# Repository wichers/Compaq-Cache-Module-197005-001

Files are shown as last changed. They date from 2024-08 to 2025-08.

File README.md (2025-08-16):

# Compaq 197005-001 Cache Module reproduction
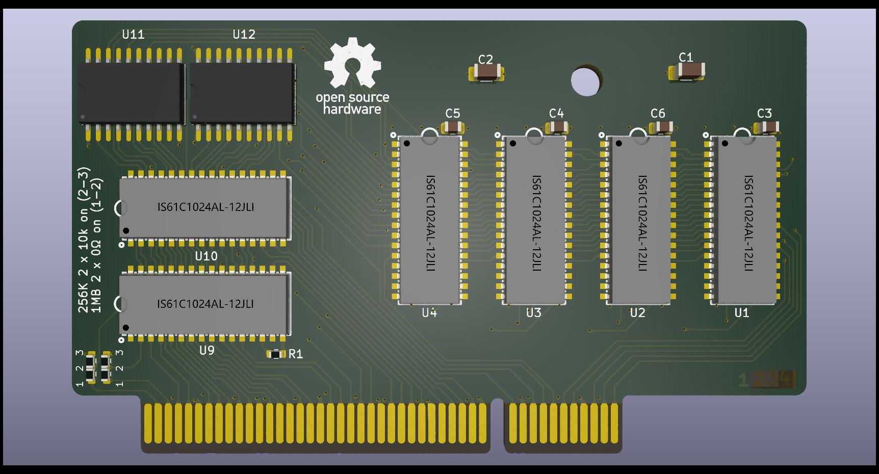
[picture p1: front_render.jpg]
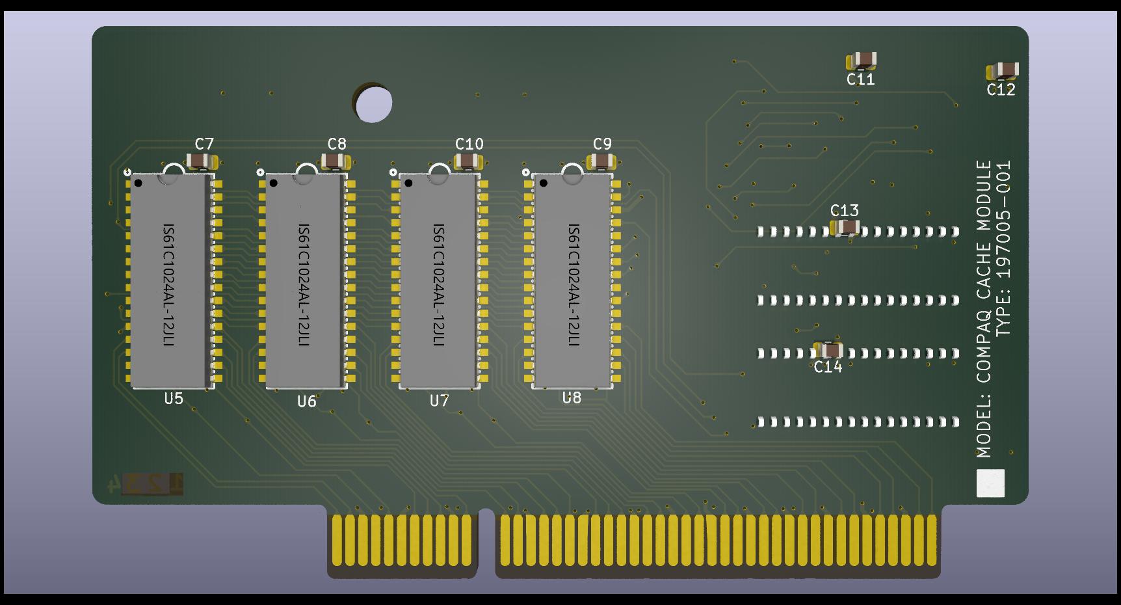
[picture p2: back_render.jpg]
[](/front_render.png?raw=true) [](/back_render.png?raw=true)

Reverse Engineered non standard 256KB/1MB L2 Cache Module for use in:

- [Compaq ProLinea 4/66 (164560-001)](https://theretroweb.com/motherboards/s/compaq-prolinea-4-66)
- [Compaq Presario 833CDS/850/850CDS/860CDS/866 (197023-001)](https://theretroweb.com/motherboards/s/compaq-presario-800)
- [Compaq Presario 700-900 series](https://theretroweb.com/motherboards/s/compaq-presario-700-900-series-486)

# Resources
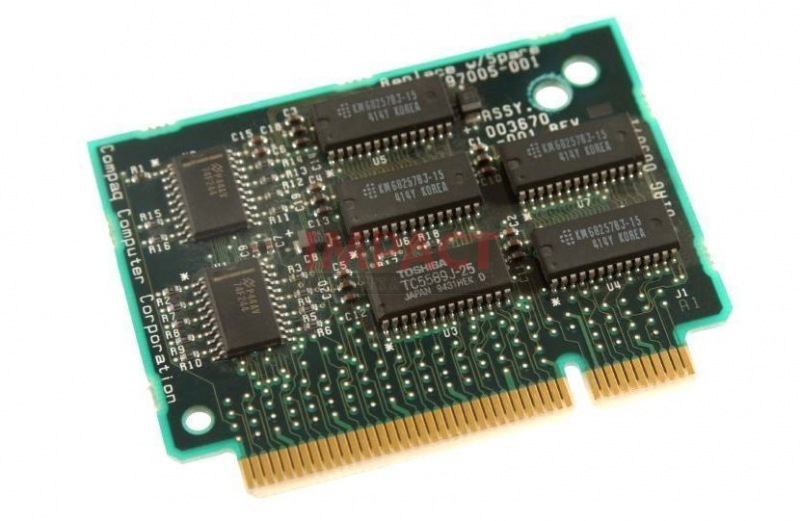
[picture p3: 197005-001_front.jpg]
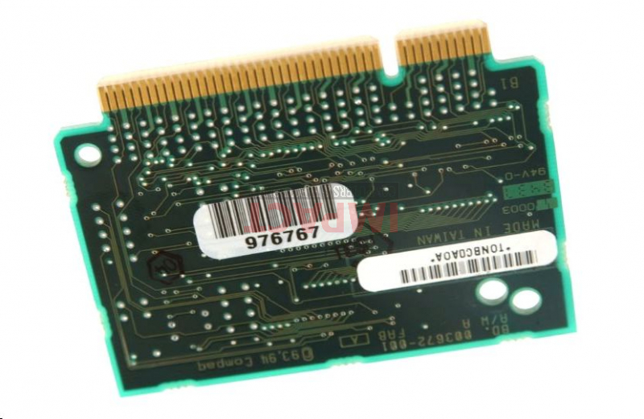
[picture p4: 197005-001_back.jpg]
Original 128KB module [front ](/197005-001_front.jpg?raw=true), [back ](/197005-001_back.jpg?raw=true)

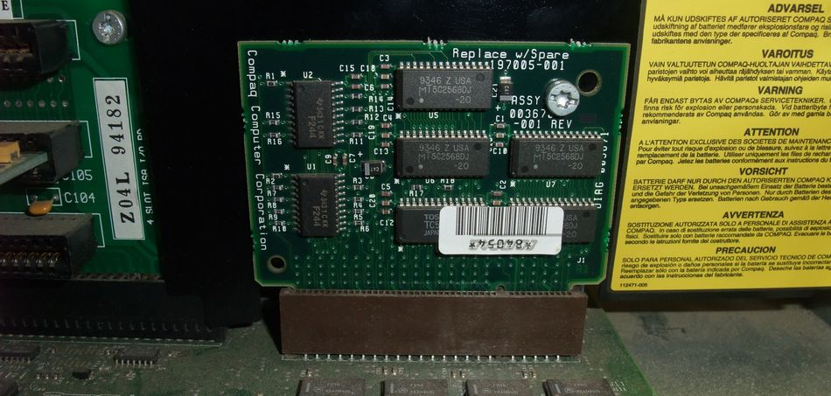
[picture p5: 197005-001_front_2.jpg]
[plugged into Prolinea 4/100](/197005-001_front_2.jpg?raw=true)

-----
This project was possible with help provided by rasz_pl - creator of the - [FIC-486-GAC-2 Cache Module reproduction](https://github.com/raszpl/FIC-486-GAC-2-Cache-Module). Huge thank you for inspiration and taking time to review.

[VL82C481 datasheet](/vl82c481-633364566fabe183309250.pdf)

[VESA VLB slot pinout](/VLB_pins.png) [VESA VLB slot dimensions](/vlb-edge-conn.png)

# Progress report

16/8/2025: Added switch to set memory size

31/8/2024: Added support for switchable 256KB/1MB

28/8/2024: First version up for testing.

23/8/2024: Project start. Figuring out the pinout and matching to datasheet.

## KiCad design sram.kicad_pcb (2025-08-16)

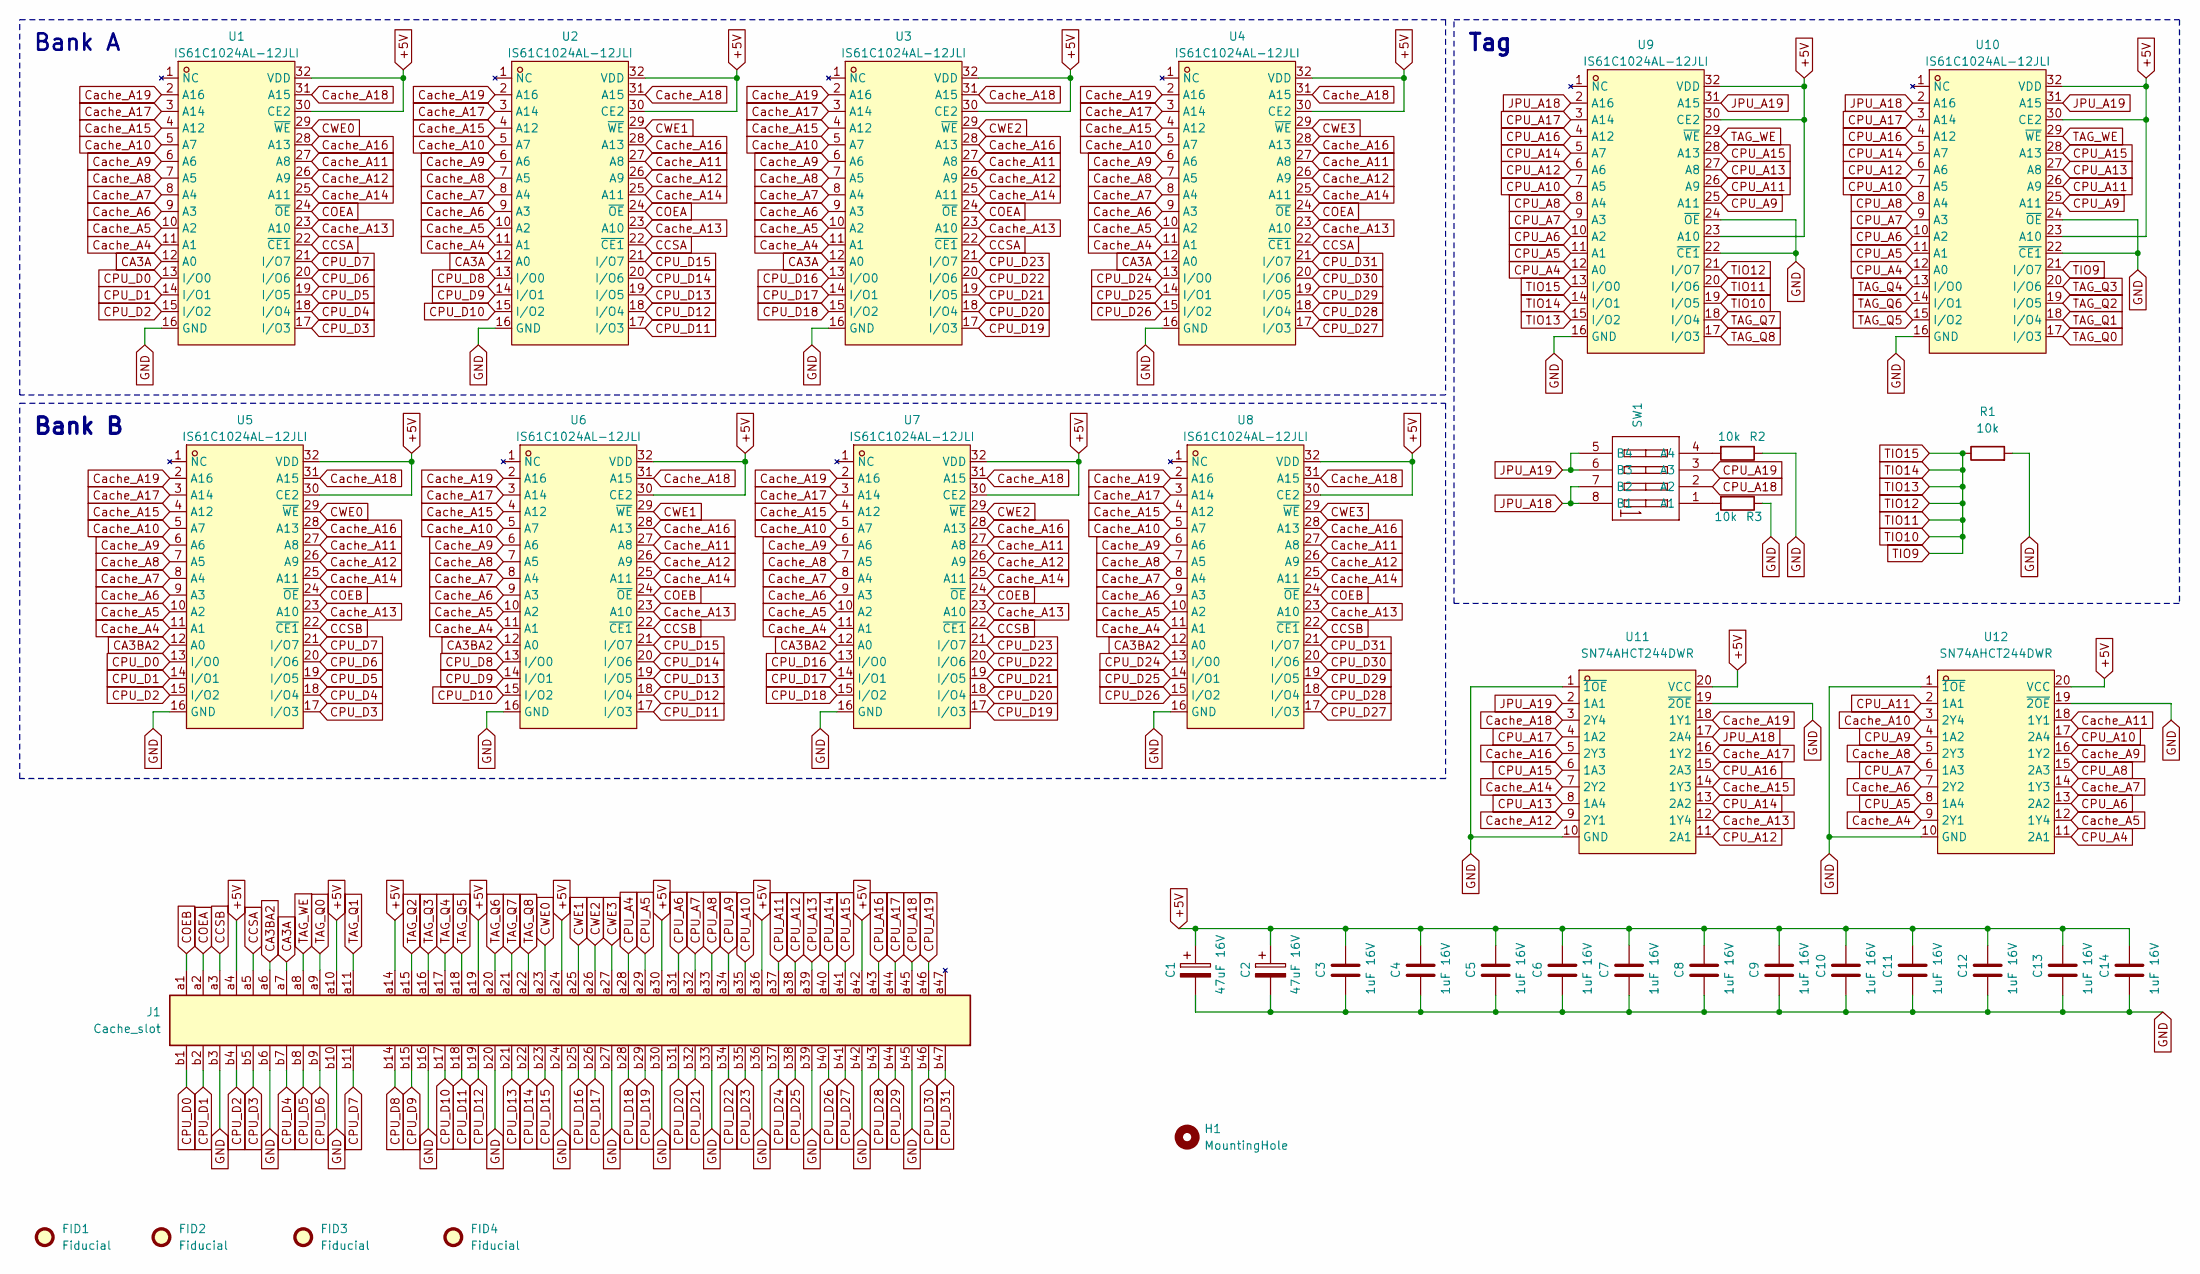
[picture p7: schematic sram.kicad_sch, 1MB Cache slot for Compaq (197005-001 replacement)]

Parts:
C1, C2: 47uF 16V; C_1206_3216Metric_Pad1.33x1.80mm_HandSolder
C3, C4, C5, C6, C7, C8, C9, C10, C11, C12, C13, C14: 1uF 16V; C_0805_2012Metric
FID1, FID2, FID3, FID4: Fiducial; Fiducial_0.5mm_Mask1mm
H1: MountingHole; MountingHole_4mm
J1: Cache_slot; Cache slot
R1, R2, R3: 10k; R_0603_1608Metric
SW1: DSIC04TSGET; SW-SMD_8P-L11.1-W6.2-P2.54-LS9.8; LCSC Part C126850
U1, U2, U3, U4, U5, U6, U7, U8, U9, U10: IS61C1024AL-12JLI; SOJ-32_L21.0-W7.6-P1.27-LS8.5-BL; LCSC Part C412832
U11, U12: SN74AHCT244DWR; SOIC-20_L12.8-W7.5-P1.27-LS10.3-BL; LCSC Part C2675568

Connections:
+5V: C1.1, C2.1, C3.1, C4.1, C5.1, C6.1, C7.1, C8.1, C9.1, C10.1, C11.1, C12.1, C13.1, C14.1, J1.a4, J1.a10, J1.a14, J1.a19, J1.a24, J1.a30, J1.a36, J1.a42, U1.30 (CE2), U1.32 (VDD), U2.30 (CE2), U2.32 (VDD), U3.30 (CE2), U3.32 (VDD), U4.30 (CE2), U4.32 (VDD), U5.30 (CE2), U5.32 (VDD), U6.30 (CE2), U6.32 (VDD), U7.30 (CE2), U7.32 (VDD), U8.30 (CE2), U8.32 (VDD), U9.23 (A10), U9.30 (CE2), U9.32 (VDD), U10.23 (A10), U10.30 (CE2), U10.32 (VDD), U11.20 (VCC), U12.20 (VCC)
CA3A: J1.a7, U1.12 (A0), U2.12 (A0), U3.12 (A0), U4.12 (A0)
CA3BA2: J1.a6, U5.12 (A0), U6.12 (A0), U7.12 (A0), U8.12 (A0)
CCSA: J1.a5, U1.22 (~CE1), U2.22 (~CE1), U3.22 (~CE1), U4.22 (~CE1)
CCSB: J1.a3, U5.22 (~CE1), U6.22 (~CE1), U7.22 (~CE1), U8.22 (~CE1)
COEA: J1.a2, U1.24 (~OE), U2.24 (~OE), U3.24 (~OE), U4.24 (~OE)
COEB: J1.a1, U5.24 (~OE), U6.24 (~OE), U7.24 (~OE), U8.24 (~OE)
CPU_A4: J1.a28, U9.12 (A0), U10.12 (A0), U12.11 (2A1)
CPU_A5: J1.a29, U9.11 (A1), U10.11 (A1), U12.8 (1A4)
CPU_A6: J1.a31, U9.10 (A2), U10.10 (A2), U12.13 (2A2)
CPU_A7: J1.a32, U9.9 (A3), U10.9 (A3), U12.6 (1A3)
CPU_A8: J1.a33, U9.8 (A4), U10.8 (A4), U12.15 (2A3)
CPU_A9: J1.a34, U9.25 (A11), U10.25 (A11), U12.4 (1A2)
CPU_A10: J1.a35, U9.7 (A5), U10.7 (A5), U12.17 (2A4)
CPU_A11: J1.a37, U9.26 (A9), U10.26 (A9), U12.2 (1A1)
CPU_A12: J1.a38, U9.6 (A6), U10.6 (A6), U11.11 (2A1)
CPU_A13: J1.a39, U9.27 (A8), U10.27 (A8), U11.8 (1A4)
CPU_A14: J1.a40, U9.5 (A7), U10.5 (A7), U11.13 (2A2)
CPU_A15: J1.a41, U9.28 (A13), U10.28 (A13), U11.6 (1A3)
CPU_A16: J1.a43, U9.4 (A12), U10.4 (A12), U11.15 (2A3)
CPU_A17: J1.a44, U9.3 (A14), U10.3 (A14), U11.4 (1A2)
CPU_A18: J1.a45, SW1.2 (A2)
CPU_A19: J1.a46, SW1.3 (A3)
CPU_D0: J1.b1, U1.13 (I/O0), U5.13 (I/O0)
CPU_D1: J1.b2, U1.14 (I/O1), U5.14 (I/O1)
CPU_D2: J1.b4, U1.15 (I/O2), U5.15 (I/O2)
CPU_D3: J1.b5, U1.17 (I/O3), U5.17 (I/O3)
CPU_D4: J1.b7, U1.18 (I/O4), U5.18 (I/O4)
CPU_D5: J1.b8, U1.19 (I/O5), U5.19 (I/O5)
CPU_D6: J1.b9, U1.20 (I/O6), U5.20 (I/O6)
CPU_D7: J1.b11, U1.21 (I/O7), U5.21 (I/O7)
CPU_D8: J1.b14, U2.13 (I/O0), U6.13 (I/O0)
CPU_D9: J1.b15, U2.14 (I/O1), U6.14 (I/O1)
CPU_D10: J1.b17, U2.15 (I/O2), U6.15 (I/O2)
CPU_D11: J1.b18, U2.17 (I/O3), U6.17 (I/O3)
CPU_D12: J1.b19, U2.18 (I/O4), U6.18 (I/O4)
CPU_D13: J1.b21, U2.19 (I/O5), U6.19 (I/O5)
CPU_D14: J1.b22, U2.20 (I/O6), U6.20 (I/O6)
CPU_D15: J1.b23, U2.21 (I/O7), U6.21 (I/O7)
CPU_D16: J1.b25, U3.13 (I/O0), U7.13 (I/O0)
CPU_D17: J1.b26, U3.14 (I/O1), U7.14 (I/O1)
CPU_D18: J1.b28, U3.15 (I/O2), U7.15 (I/O2)
CPU_D19: J1.b29, U3.17 (I/O3), U7.17 (I/O3)
CPU_D20: J1.b31, U3.18 (I/O4), U7.18 (I/O4)
CPU_D21: J1.b32, U3.19 (I/O5), U7.19 (I/O5)
CPU_D22: J1.b34, U3.20 (I/O6), U7.20 (I/O6)
CPU_D23: J1.b35, U3.21 (I/O7), U7.21 (I/O7)
CPU_D24: J1.b37, U4.13 (I/O0), U8.13 (I/O0)
CPU_D25: J1.b38, U4.14 (I/O1), U8.14 (I/O1)
CPU_D26: J1.b40, U4.15 (I/O2), U8.15 (I/O2)
CPU_D27: J1.b41, U4.17 (I/O3), U8.17 (I/O3)
CPU_D28: J1.b43, U4.18 (I/O4), U8.18 (I/O4)
CPU_D29: J1.b44, U4.19 (I/O5), U8.19 (I/O5)
CPU_D30: J1.b46, U4.20 (I/O6), U8.20 (I/O6)
CPU_D31: J1.b47, U4.21 (I/O7), U8.21 (I/O7)
CWE0: J1.a23, U1.29 (~WE), U5.29 (~WE)
CWE1: J1.a25, U2.29 (~WE), U6.29 (~WE)
CWE2: J1.a26, U3.29 (~WE), U7.29 (~WE)
CWE3: J1.a27, U4.29 (~WE), U8.29 (~WE)
Cache_A4: U1.11 (A1), U2.11 (A1), U3.11 (A1), U4.11 (A1), U5.11 (A1), U6.11 (A1), U7.11 (A1), U8.11 (A1), U12.9 (2Y1)
Cache_A5: U1.10 (A2), U2.10 (A2), U3.10 (A2), U4.10 (A2), U5.10 (A2), U6.10 (A2), U7.10 (A2), U8.10 (A2), U12.12 (1Y4)
Cache_A6: U1.9 (A3), U2.9 (A3), U3.9 (A3), U4.9 (A3), U5.9 (A3), U6.9 (A3), U7.9 (A3), U8.9 (A3), U12.7 (2Y2)
Cache_A7: U1.8 (A4), U2.8 (A4), U3.8 (A4), U4.8 (A4), U5.8 (A4), U6.8 (A4), U7.8 (A4), U8.8 (A4), U12.14 (1Y3)
Cache_A8: U1.7 (A5), U2.7 (A5), U3.7 (A5), U4.7 (A5), U5.7 (A5), U6.7 (A5), U7.7 (A5), U8.7 (A5), U12.5 (2Y3)
Cache_A9: U1.6 (A6), U2.6 (A6), U3.6 (A6), U4.6 (A6), U5.6 (A6), U6.6 (A6), U7.6 (A6), U8.6 (A6), U12.16 (1Y2)
Cache_A10: U1.5 (A7), U2.5 (A7), U3.5 (A7), U4.5 (A7), U5.5 (A7), U6.5 (A7), U7.5 (A7), U8.5 (A7), U12.3 (2Y4)
Cache_A11: U1.27 (A8), U2.27 (A8), U3.27 (A8), U4.27 (A8), U5.27 (A8), U6.27 (A8), U7.27 (A8), U8.27 (A8), U12.18 (1Y1)
Cache_A12: U1.26 (A9), U2.26 (A9), U3.26 (A9), U4.26 (A9), U5.26 (A9), U6.26 (A9), U7.26 (A9), U8.26 (A9), U11.9 (2Y1)
Cache_A13: U1.23 (A10), U2.23 (A10), U3.23 (A10), U4.23 (A10), U5.23 (A10), U6.23 (A10), U7.23 (A10), U8.23 (A10), U11.12 (1Y4)
Cache_A14: U1.25 (A11), U2.25 (A11), U3.25 (A11), U4.25 (A11), U5.25 (A11), U6.25 (A11), U7.25 (A11), U8.25 (A11), U11.7 (2Y2)
Cache_A15: U1.4 (A12), U2.4 (A12), U3.4 (A12), U4.4 (A12), U5.4 (A12), U6.4 (A12), U7.4 (A12), U8.4 (A12), U11.14 (1Y3)
Cache_A16: U1.28 (A13), U2.28 (A13), U3.28 (A13), U4.28 (A13), U5.28 (A13), U6.28 (A13), U7.28 (A13), U8.28 (A13), U11.5 (2Y3)
Cache_A17: U1.3 (A14), U2.3 (A14), U3.3 (A14), U4.3 (A14), U5.3 (A14), U6.3 (A14), U7.3 (A14), U8.3 (A14), U11.16 (1Y2)
Cache_A18: U1.31 (A15), U2.31 (A15), U3.31 (A15), U4.31 (A15), U5.31 (A15), U6.31 (A15), U7.31 (A15), U8.31 (A15), U11.3 (2Y4)
Cache_A19: U1.2 (A16), U2.2 (A16), U3.2 (A16), U4.2 (A16), U5.2 (A16), U6.2 (A16), U7.2 (A16), U8.2 (A16), U11.18 (1Y1)
GND: C1.2, C2.2, C3.2, C4.2, C5.2, C6.2, C7.2, C8.2, C9.2, C10.2, C11.2, C12.2, C13.2, C14.2, J1.b3, J1.b6, J1.b10, J1.b16, J1.b20, J1.b24, J1.b27, J1.b30, J1.b33, J1.b36, J1.b39, J1.b42, J1.b45, R1.2, R2.1, R3.1, U1.16 (GND), U2.16 (GND), U3.16 (GND), U4.16 (GND), U5.16 (GND), U6.16 (GND), U7.16 (GND), U8.16 (GND), U9.16 (GND), U9.22 (~CE1), U9.24 (~OE), U10.16 (GND), U10.22 (~CE1), U10.24 (~OE), U11.1 (~1OE), U11.10 (GND), U11.19 (~2OE), U12.1 (~1OE), U12.10 (GND), U12.19 (~2OE)
JPU_A18: SW1.7 (B2), SW1.8 (B1), U9.2 (A16), U10.2 (A16), U11.17 (2A4)
JPU_A19: SW1.5 (B4), SW1.6 (B3), U9.31 (A15), U10.31 (A15), U11.2 (1A1)
unnamed: R3.2, SW1.1 (A1)
unnamed: R2.2, SW1.4 (A4)
TAG_Q0: J1.a9, U10.17 (I/O3)
TAG_Q1: J1.a11, U10.18 (I/O4)
TAG_Q2: J1.a15, U10.19 (I/O5)
TAG_Q3: J1.a16, U10.20 (I/O6)
TAG_Q4: J1.a17, U10.13 (I/O0)
TAG_Q5: J1.a18, U10.15 (I/O2)
TAG_Q6: J1.a20, U10.14 (I/O1)
TAG_Q7: J1.a21, U9.18 (I/O4)
TAG_Q8: J1.a22, U9.17 (I/O3)
TAG_WE: J1.a8, U9.29 (~WE), U10.29 (~WE)
TIO10: R1.1, U9.13 (I/O0), U9.14 (I/O1), U9.15 (I/O2), U9.19 (I/O5), U9.20 (I/O6), U9.21 (I/O7), U10.21 (I/O7)

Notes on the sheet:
Bank A
Tag
Bank B

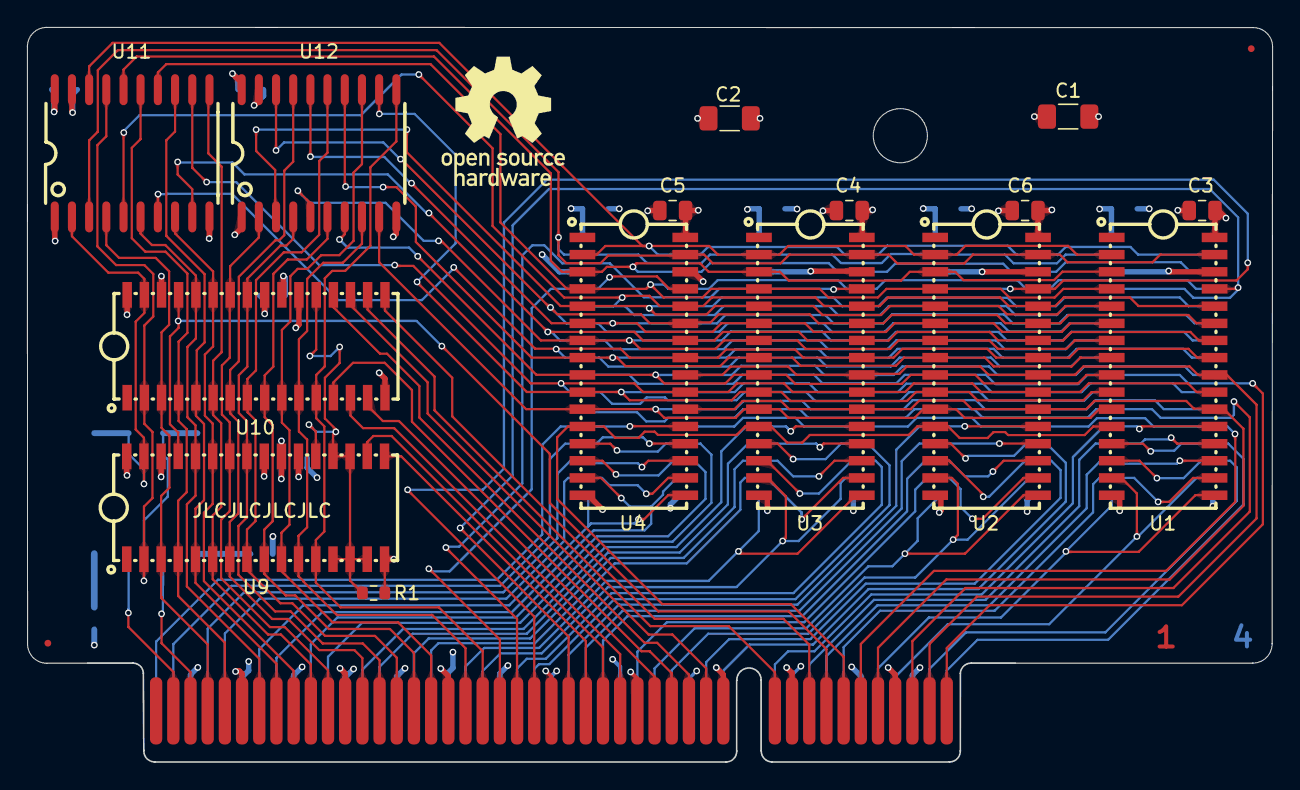
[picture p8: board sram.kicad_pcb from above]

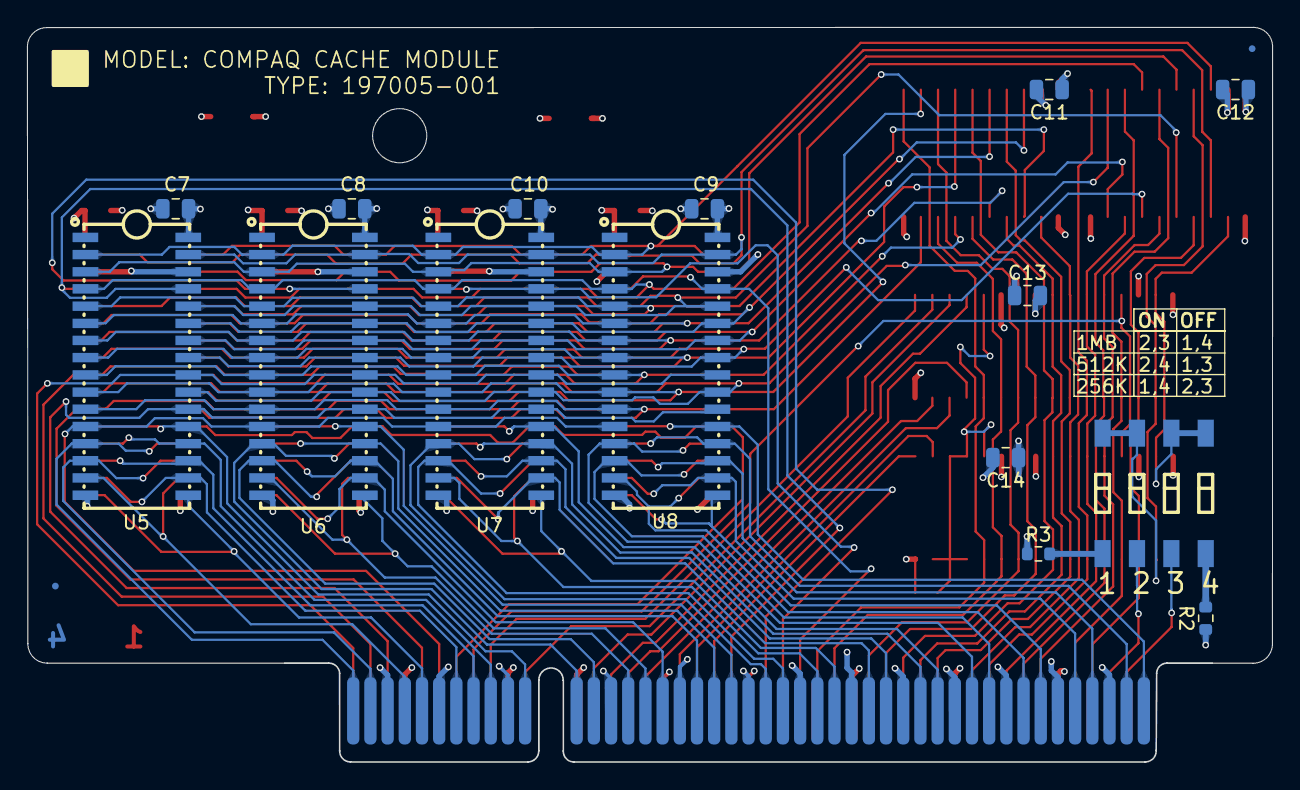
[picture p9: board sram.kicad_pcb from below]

Board: 4 copper layers, 92.0 x 54.3 mm, 36 parts (17 on the bottom side), 91 nets.

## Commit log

2024-08-28 inital commit
    [sram-B_Cu.gbr, sram-B_Mask.gbr, sram-B_Silkscreen.gbr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]
2024-08-29 change from rasz_pl: - moving VIAs apart - change resistor network with single resistor
    [sram.kicad_pcb, sram.kicad_sch]
2024-08-30 pass DRC with rounded tracks
    [sram-B_Cu.gbr, sram-B_Mask.gbr, sram-B_Silkscreen.gbr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]
2024-08-31 updated to 256KB/1MB
    [sram-B_Cu.gbr, sram-B_Mask.gbr, sram-B_Silkscreen.gbr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]
2024-08-31 Added support for switchable 256KB/1MB
2025-08-16 added switch to set memory size
    [sram-B_Cu.gbl, sram-B_Cu.gbr, sram-B_Mask.gbs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]
